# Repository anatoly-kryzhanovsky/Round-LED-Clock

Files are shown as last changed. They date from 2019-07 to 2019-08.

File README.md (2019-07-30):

# Arduino Round-LED Clock 
 Project based on awesome project <a href="https://github.com/leonvandenbeukel/Round-LED-Clock">Wi-Fi Connected Round-LED-Clock</a>
 
 # Changes from original
 1) move to <a href="https://platformio.org">PlatformIO</a> editor and split projects to separate classes
 2) support different timesources (RTC, NTP based or custom provided by your code)
 3) add new model (in progress) and PCB for RTC-based case
 4) add control block for adjust time
  
 ## Schema
 
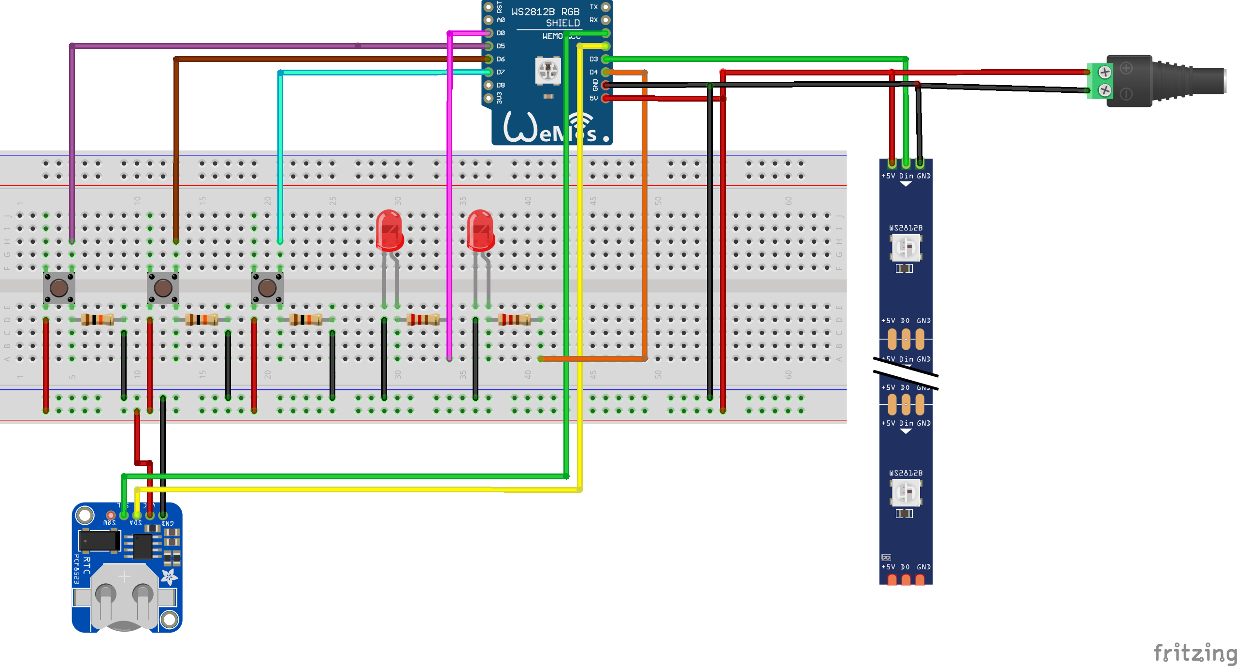
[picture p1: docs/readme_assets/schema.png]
  
 
 Connection:
 * connect 5 volts from power source to Vin pin of arduino board (Vcc, 5V, Vin,...)
 * connect 5 volts from power source to +5V of led strip
 * connect 5 volts from power source to Vcc pin of DS1307 RTC board
 * connect 5 volts from power source to three switches
 * connect Ground from power source to Gnd pin of arduino board
 * connect Ground from power source to Gnd pin of led strip
 * connect Ground from power source to Gnd pin of DS1307 RTC board
 * connect Ground from power source to another pin of switches throught 10k ohm resisors
 * connect Ground from power source to cathode (shortes) pin of two leds
 * connect three switches to digital pins of arduino board (can be any not used digital pin - pins number are configurable through code)
 * connect led anode through 220 ohm resistor to another digital pin of arduino board
 * connect SDA and SCL pins of DS1307 board to corresponding pins of your arduino board (I2C bus)
 * connect led strip data pin to not used digital pin of arduino board.  

## Notes

* There are two level of debounce - hardware (using pull-up resistor for switches) and software (using bounce2 library). You can ommit hardware part for simplification.
* You can use RTC timesource or NTP. For NTP you must have Wi-Fi with Internet access. Current NTP time source code witks only with Wemos board based on ESP8266.
* There are 60 leds in strip, each led consume 0.3W, so if you want to turn all of them you need at least 18W power adapter (with 5V). In my configuration only 3 leds turn on at same time (hour, minute and second), so i need only 0.9W or ~0.2A, so i use power adapter from my old phone.
* Be attention with power source - all units in scheme use 5V and can burn out from higher voltage
  
## Parts list (just Google on the name to find a link where to buy)

| Image | Count | Components|
| ---|---|---|
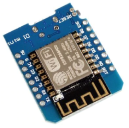
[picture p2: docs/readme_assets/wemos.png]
|  | 1 |WeMOS D1 Mini ESP module (if you want to use NTP sync) |
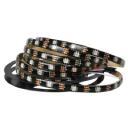
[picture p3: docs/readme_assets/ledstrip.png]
|  | 1 |LED strip WS2812B 60 RGB LED's 1 meter |
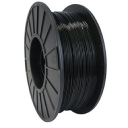
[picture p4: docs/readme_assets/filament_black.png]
|  | X | Black PLA filament |
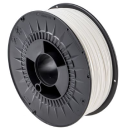
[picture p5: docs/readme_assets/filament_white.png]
|  | X | White PLA filament |
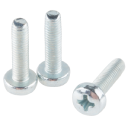
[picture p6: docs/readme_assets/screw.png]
|  | 4 | M3 screws |
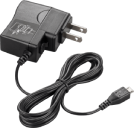
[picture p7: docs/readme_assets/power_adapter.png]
|   | 1| Power adapter (5V DC, 0.5A) |
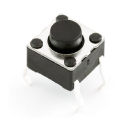
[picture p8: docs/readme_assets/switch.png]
|  | 3 | switch |
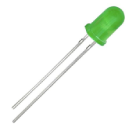
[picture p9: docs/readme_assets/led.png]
|  | 2 | leds (5V) |
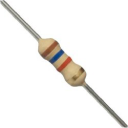
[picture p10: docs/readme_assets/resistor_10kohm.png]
|  | 3 | resistors of 10kOm |
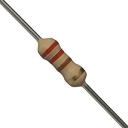
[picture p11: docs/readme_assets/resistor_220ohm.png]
|  | 2 | resistors of 220Om |
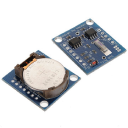
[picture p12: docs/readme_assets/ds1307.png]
|  | 1 | DS1307 RTC if you want to use RTC sync) |
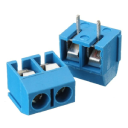
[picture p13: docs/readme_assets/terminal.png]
|  | 2 | 2 power terminal) |
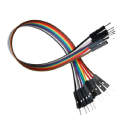
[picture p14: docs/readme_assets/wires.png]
|  | X | Jumper wires |

## YouTube video (in progress)

<a href="https://youtu.be/Z4b4v84smpg" target="_blank">Click to view: LED Clock</a>

## Configuration

All configuration stored in [LedClock/src/configuration.hpp](LedClock/src/configuration.hpp) file.

There are configurations for different part of the system:

### Control configuration (ControlConfiguration class)

* ModeButtonPin - number of digital pin where mode button was connected. Mode button allow change mode of control block. By default control block disabled. If you press mode button once then you enter to hour ajustment mode and can use increase or decrease buttons for add or substract one hour to current time. If you press mode button again then you enter to minute adjustment mode and can use increase or decrease buttons for add or substract one minute to current time. If you press mode button again you exit from edit mode and return to initial state. There is timeout for autoexit from edit mode - if you not press any button in *EditModeTimeout* period then system exit from ediit mode and return to initial state.
* IncreaseButtonPin - number of digital pin where increate button was connected. In edit mode (hour or minute) you can use this button for add one minute to current time.
* DecreaseButtonPin - number of digital pin where decrease button was connected. In edit mode (hour or minute) you can use this button for subtract one minute to current time.
* HourModeLedPin - number of digital pin where hour mode led was connected. In edit mode while you adjust hour this led is on.
* MinuteModeLedPin - number of digital pin where minute mode led was connected. In edit mode while you adjust minute this led is on.
* EditModeTimeout - timeout (in millis) for autoexit from edit mode.
* ButtonDebounceInterval - interval (in millis) for buttons debounce (used by Bounce2 library)

### Clockfact configuration (ClockFaceConfiguration class)

* HourSmoothMove - if true then at 20 minutes hour led should be at second led in hour group, if false then hour led move only after 59 minutes 59 seconds reached
* UseNightMode - use different brightness for night time (defined by *NightStartAt* and *NightEndAt*)
* NightEndAt - hours then nightmode should disabled (in 24 hour notation)
* NightStartAt - hours then nightmode should enabled (in 24 hour notation)
* NightmodeBrightness - brightness for nightmode (from 0 to 255, where 0 turn leds off and 255 - use maximum brightnes)
* LedsCount - count of leds in strip
* LedDataPin - number of digital pin where led strip data pin was connected
* ColorHour - color for hour led
* ColorMinute - color for minute led
* ColorSecond - color for second led
* ColorHourMinute - color for led if hour and minute has same position
* ColorMinuteSecond - color for led if minute and second has same position
* ColorAll - color for led if hour, minute and second has same position

### RTC timesource configuration (RtcTimeSourceConfiguration class)

* SyntInterval - interval (in millis) for synchornization internal clock (calculated by system millis() function) and external RTC

### NTP timesource configuration (NtpTimeSourceConfiguration class)

* NTPServerName - NTP server name (server should be available through WiFi)
* SSID - ssid of WiFi network
* Password - key for connect to WiFi network
* TimeZone - local timezone 
* SyncInterval - interval (in millis) for synchronization with NTP server 

### System-wide configuration (SystemConfiguration class)

* TickTime - delay (in millis) between loop iteration

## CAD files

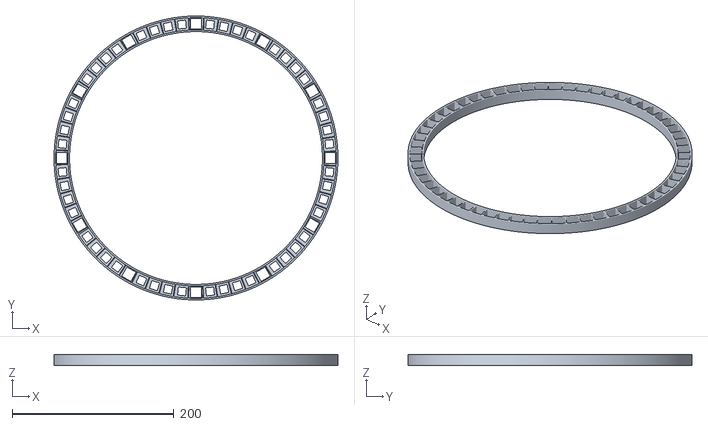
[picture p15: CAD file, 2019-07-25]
docs/STL/Segment complete thicker wall.stl
350.9 x 350.9 x 13.2

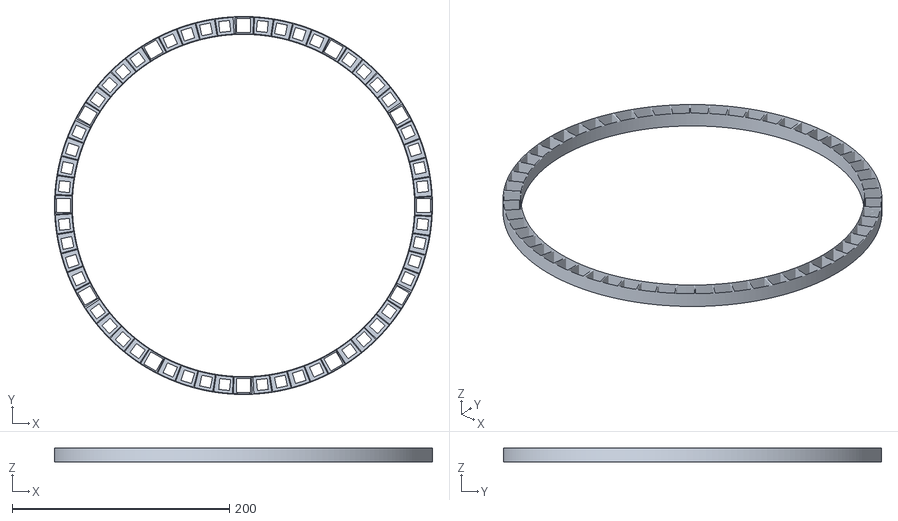
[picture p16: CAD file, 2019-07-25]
docs/STL/Segment complete.stl
348.1 x 348.1 x 13.2

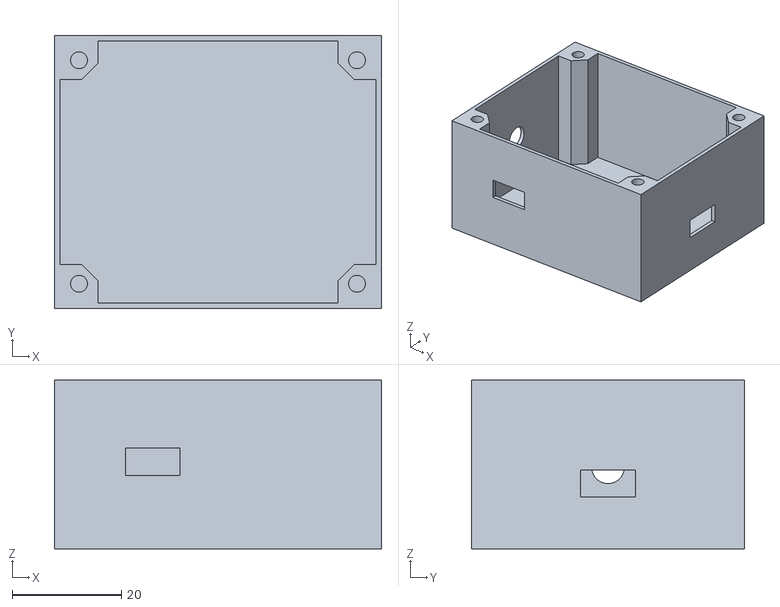
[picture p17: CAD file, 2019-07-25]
docs/STL/Box.stl
60.0 x 50.0 x 31.0

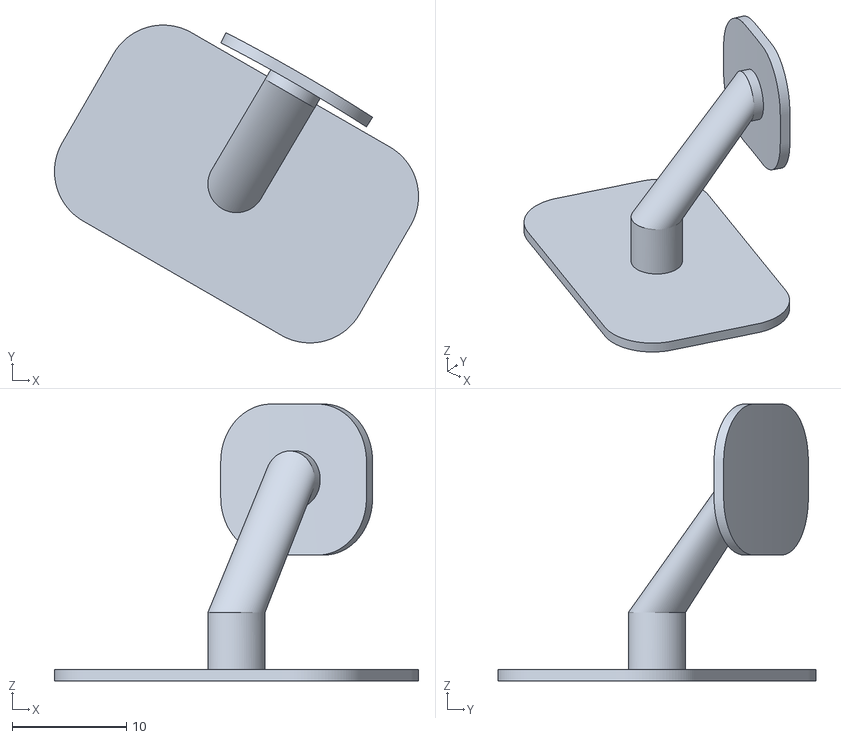
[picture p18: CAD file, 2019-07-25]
docs/STL/Holder Small.stl
31.8 x 27.8 x 24.2

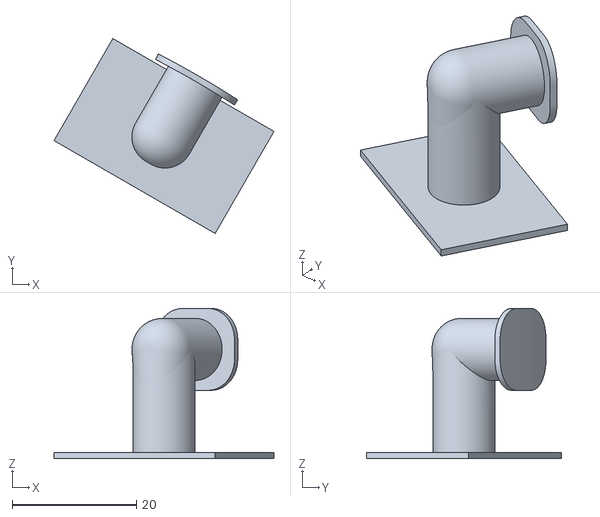
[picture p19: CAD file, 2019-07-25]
docs/STL/Holder Large.stl
35.5 x 31.4 x 24.2

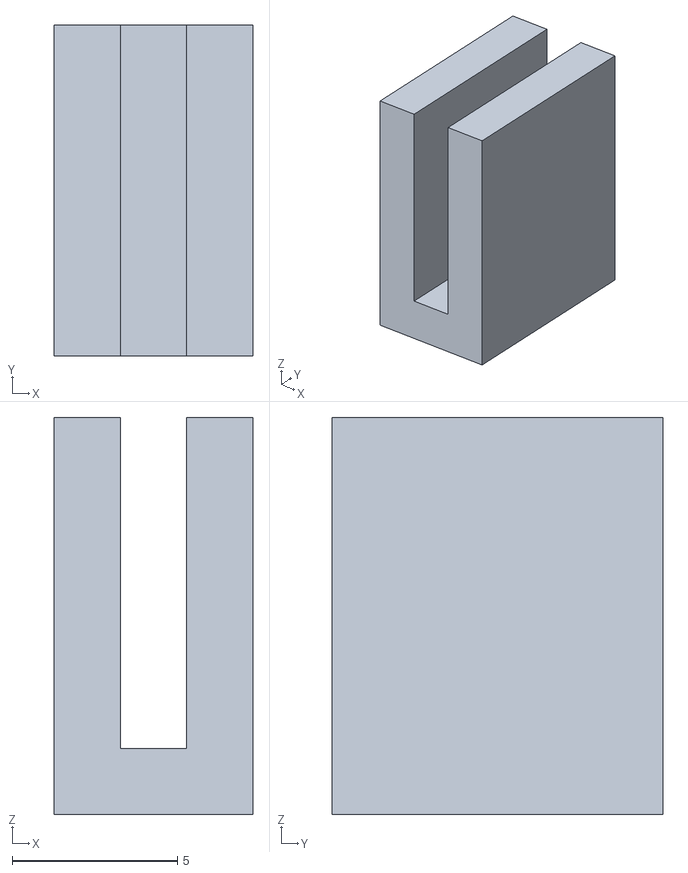
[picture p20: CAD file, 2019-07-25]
docs/STL/lock.STL
6.00 x 10.0 x 12.0

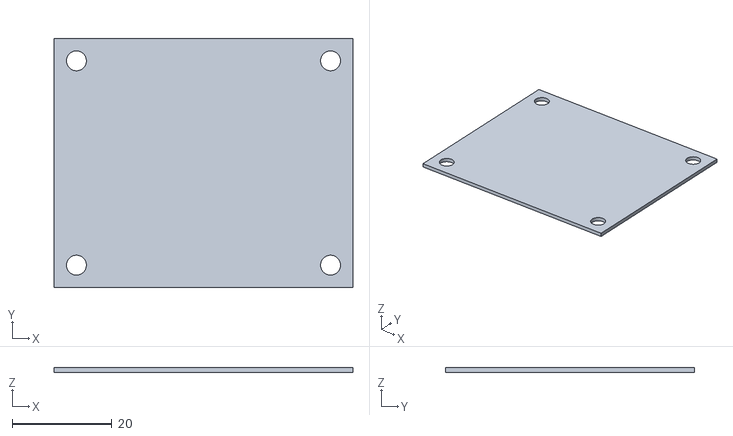
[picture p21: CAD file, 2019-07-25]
docs/STL/Lid.stl
60.0 x 50.0 x 1.00

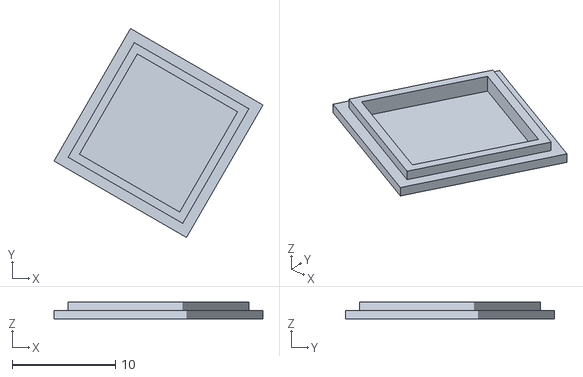
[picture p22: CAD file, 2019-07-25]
docs/STL/Cover Large.stl
20.2 x 20.2 x 1.60

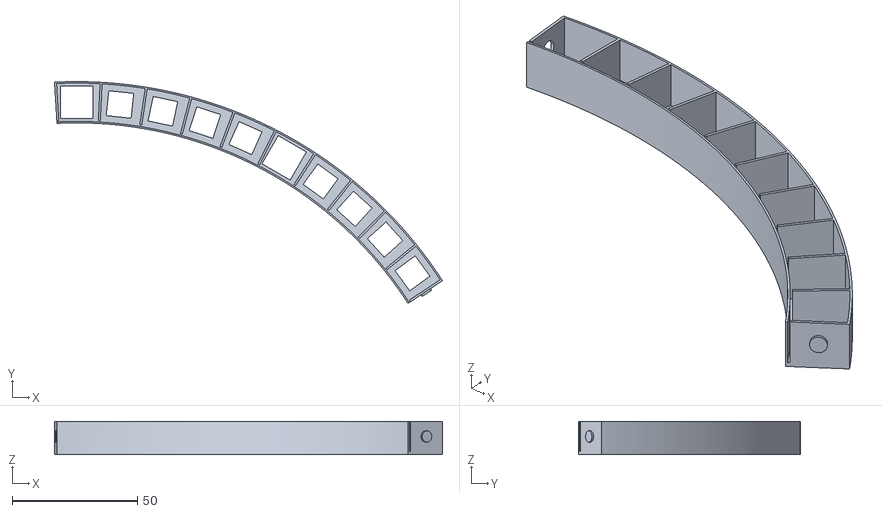
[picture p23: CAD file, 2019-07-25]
docs/STL/Segment.stl
154.9 x 88.6 x 13.2

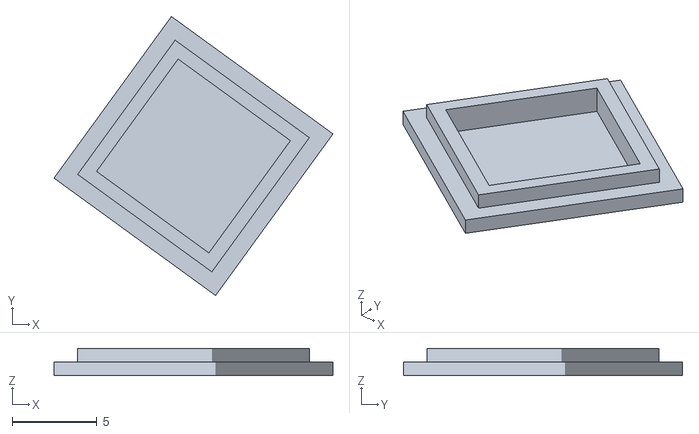
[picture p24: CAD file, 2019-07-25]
docs/STL/Cover Small.stl
16.5 x 16.5 x 1.60

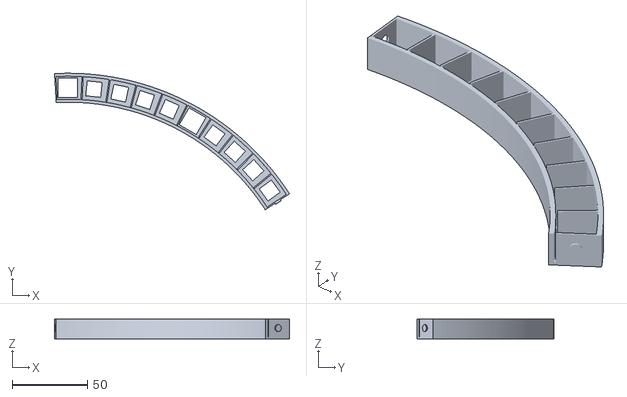
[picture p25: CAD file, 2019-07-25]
docs/STL/Segment thicker wall.stl
156.2 x 90.7 x 13.2

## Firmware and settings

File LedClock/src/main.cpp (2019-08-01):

#include <Arduino.h>

#include <time.hpp>
#include <rtcTimeSource.hpp>
#include <ntpTimeSource.hpp>
#include <clockControl.hpp>
#include <clockFace.hpp>
#include <configuration.hpp>

#define DEBUG

RtcTimeSource timeSource;
//NtpTimeSource timeSource;

ClockControl control(&timeSource);
ClockFace clockFace;

unsigned long lastDebugTime = 0;

void setup() {
  Serial.begin(115200);

  control.init();
  timeSource.init();
  clockFace.init();
}

void loop() {
  timeSource.updateTime();
  control.update();
  clockFace.showTime(timeSource.getCurrentTime());

#ifdef DEBUG
  if(millis() - lastDebugTime > 5000)
  {
    lastDebugTime = millis();
    Serial.println("TimeSource state");
    Serial.println(timeSource.toString());
    Serial.println("Control state");
    Serial.println(control.toString());
    Serial.println("ClockFace state");
    Serial.println(clockFace.toString());
  }
#endif
 
  delay(Configuration::SystemConfiguration::TickTime);
}

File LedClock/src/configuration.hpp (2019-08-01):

#pragma once

#include <FastLED.h>

class Configuration {
    public:
    //configuration for control module
    class ControlConfiguration {
        public:
            //pin number for mode button (none/clock/minutes control)
            static const int ModeButtonPin           = D6;

            //pin number for increase button (add hour or minute)
            static const int IncreaseButtonPin       = D5;

            //pin number for decrease button (substract hour or minute)
            static const int DecreaseButtonPin       = D0;

            //pin number for set hours mode led
            static const int HourModeLedPin          = D4;

            //pin number for set minutes mode led
            static const int MinuteModeLedPin        = D3;

            //timeout (in millis) for autoexit from set time mode
            static const int EditModeTimeout         = 5000;

            //edbounce interval for Bounce2 (millis)
            static const int ButtonDebounceInterval  = 5;
    };

    //configuration for clockface
    class ClockFaceConfiguration {
        public:        
            //led number for zero count
            static const int ZeroLed                 = 30;

            //direction for leds numbering (+1 for clockwise, -1 for counterclockwise)
            static const int Direction               = -1;

            //enable move hour led between interger parts (i.e. if true then at 20 minutes hour led should be at second led in hour group, if false then hour led move only after 59 minutes 59 seconds reached)
            static const bool HourSmoothMove         = true;

            //use different brightness for night hours
            static const bool UseNightMode           = false;

            //hours when night node should be deactivated
            static const int NightEndAt              = 8;

            //hours when night node should be activated
            static const int NightStartAt            = 20;

            //brightness for nightmod
            static const int NightModeBrightness     = 20;

            //leds count in strip
            static const int LedsCount               = 60;

            //pin for led strip data
            static const int LedDataPin              = D7;

            //color for hour led
            static const CRGB ColorHour;

            //color for minute led
            static const CRGB ColorMinute;

            //color for second led
            static const CRGB ColorSecond;

            //color for led if hours and minutes in same position
            static const CRGB ColorHourMinute;

            //color for led if hours and seconds in same position
            static const CRGB ColorHourSecond;

            //color for led if minutes and seconds in same position
            static const CRGB ColorMinuteSecond;

            //color for led if hours, minutes and seconds in same position
            static const CRGB ColorAll;
    };

    //configuration for RTC timesource
    class RtcTimeSourceConfiguration {
        public:
            //sync internal timer with timesource (millis)
            static const unsigned long SyncInterval = 60000L;
    };

    //config for NTP timesource
    class NtpTimeSourceConfiguration {
        public:
            static const char* NTPServerName;
            static const char* SSID;
            static const char* Password;
            static const unsigned long TimeZone = 1;

            //sync internal timer with timesource (millis)
            static const unsigned long SyncInterval = 60000L;
    };
        
    //global configuration
    class SystemConfiguration {
        public:
            //delay (millis) between update iteration
            static const int TickTime               = 20;
    };       
};

const CRGB Configuration::ClockFaceConfiguration::ColorHour              = CRGB::Red;
const CRGB Configuration::ClockFaceConfiguration::ColorMinute            = CRGB::Green;
const CRGB Configuration::ClockFaceConfiguration::ColorSecond            = CRGB::Blue;
const CRGB Configuration::ClockFaceConfiguration::ColorHourMinute        = CRGB::Yellow;
const CRGB Configuration::ClockFaceConfiguration::ColorHourSecond        = CRGB::Magenta;
const CRGB Configuration::ClockFaceConfiguration::ColorMinuteSecond      = CRGB::Cyan;
const CRGB Configuration::ClockFaceConfiguration::ColorAll               = CRGB::White;

const char* Configuration::NtpTimeSourceConfiguration::NTPServerName = "ntp1.stratum2.ru";
const char* Configuration::NtpTimeSourceConfiguration::SSID = "";
const char* Configuration::NtpTimeSourceConfiguration::Password = "";

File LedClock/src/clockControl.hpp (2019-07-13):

#pragma once

#include <Arduino.h>
#include <Bounce2.h>

#include <timeSource.h>
#include <configuration.hpp>

class ClockControl {        
    enum SystemMode {
        Normal,
        Hours,
        Minutes
    };

    private:
        static char* _buffer;

    private:
        TimeSource* _timeSource;
        bool _increaseButtonPressed;
        bool _decreaseButtonPressed;
        bool _modeButtonPressed;
        unsigned long _prevModeChange;
        SystemMode _currentMode;
        Bounce _modeDebouncer;
        Bounce _increaseDebouncer;
        Bounce _decreaseDebouncer;        
    
    public:
        ClockControl(TimeSource* _timeSource): 
            _timeSource(_timeSource), _increaseButtonPressed(false), _decreaseButtonPressed(false), _modeButtonPressed(false), _prevModeChange(0),  _currentMode (SystemMode::Normal) {                                   
        }

        const char* toString() {
            const char* modeName = "Normal";
            if(_currentMode == SystemMode::Hours)
                modeName = "Hours";
            if(_currentMode == SystemMode::Minutes)
                modeName = "Minutes";

            sprintf(
                _buffer, 
                "ModeButton: %s, IncreaseButton: %s, DecreaseButton: %s, CurrentState: %s, Last action time: %ld", 
                _modeButtonPressed ? "pressed": "normal",
                _increaseButtonPressed ? "pressed": "normal",
                _decreaseButtonPressed ? "pressed": "normal",
                modeName,
                millis() - _prevModeChange);            
            
            return _buffer;
        }

        void init() {
            pinMode(Configuration::ControlConfiguration::ModeButtonPin, INPUT);
            pinMode(Configuration::ControlConfiguration::IncreaseButtonPin, INPUT);
            pinMode(Configuration::ControlConfiguration::DecreaseButtonPin, INPUT);
            pinMode(Configuration::ControlConfiguration::HourModeLedPin, OUTPUT);
            pinMode(Configuration::ControlConfiguration::MinuteModeLedPin, OUTPUT);

            _modeDebouncer.attach(Configuration::ControlConfiguration::ModeButtonPin);
            _modeDebouncer.interval(Configuration::ControlConfiguration::ButtonDebounceInterval);

            _increaseDebouncer.attach(Configuration::ControlConfiguration::IncreaseButtonPin);
            _increaseDebouncer.interval(Configuration::ControlConfiguration::ButtonDebounceInterval);

            _decreaseDebouncer.attach(Configuration::ControlConfiguration::DecreaseButtonPin);
            _decreaseDebouncer.interval(Configuration::ControlConfiguration::ButtonDebounceInterval);

            _currentMode = SystemMode::Normal;

            _prevModeChange = 0;
        }

        void update() {
            _modeDebouncer.update();
            _increaseDebouncer.update();
            _decreaseDebouncer.update();

            bool modeButtonPressed = _modeDebouncer.read() == HIGH;
            if(modeButtonPressed && modeButtonPressed != _modeButtonPressed) {
                switch(_currentMode) {
                    case SystemMode::Normal:
                        _currentMode = SystemMode::Hours;
                        digitalWrite(Configuration::ControlConfiguration::HourModeLedPin, HIGH);
                        digitalWrite(Configuration::ControlConfiguration::MinuteModeLedPin, LOW);
                        break;

                    case SystemMode::Hours:
                        _currentMode = SystemMode::Minutes;
                        digitalWrite(Configuration::ControlConfiguration::HourModeLedPin, LOW);
                        digitalWrite(Configuration::ControlConfiguration::MinuteModeLedPin, HIGH);
                        break;

                    case SystemMode::Minutes:
                        _currentMode = SystemMode::Normal;
                        digitalWrite(Configuration::ControlConfiguration::HourModeLedPin, LOW);
                        digitalWrite(Configuration::ControlConfiguration::MinuteModeLedPin, LOW);
                        break;
                }

                _prevModeChange = millis();
            }

            _modeButtonPressed = modeButtonPressed;

            int dHours = 0, dMinutes = 0;
            Time currentTime = _timeSource->getCurrentTime();

            bool increaseButtonPressed = _increaseDebouncer.read() == HIGH;
            if(increaseButtonPressed && _increaseButtonPressed != increaseButtonPressed) {
                switch(_currentMode) {
                    case SystemMode::Hours:
                        dHours = 1;
                        break;

                    case SystemMode::Minutes:
                        if(currentTime.getMinutes() == 59)
                            dHours = -1;
                        dMinutes = 1;
                        break;

                    default:
                        break;
                }

                _prevModeChange = millis();
            }

            _increaseButtonPressed = increaseButtonPressed;
           
            bool decreaseButtonPressed = _decreaseDebouncer.read() == HIGH;            
            if(decreaseButtonPressed && _decreaseButtonPressed != decreaseButtonPressed) {
                switch(_currentMode) {
                    case SystemMode::Hours:
                        dHours = -1;
                        break;

                    case SystemMode::Minutes:
                        if(currentTime.getMinutes() == 0)
                            dHours = 1;
                        dMinutes = -1;
                        break;

                    default:
                        break;
                }

                _prevModeChange = millis();
            }

            _decreaseButtonPressed = decreaseButtonPressed;

            _timeSource->adjustTime(dHours, dMinutes);   

            if(millis() - _prevModeChange > Configuration::ControlConfiguration::EditModeTimeout) {
                digitalWrite(Configuration::ControlConfiguration::HourModeLedPin, LOW);
                digitalWrite(Configuration::ControlConfiguration::MinuteModeLedPin, LOW);
                _currentMode = SystemMode::Normal;
            }         
        }        
};

char* ClockControl::_buffer = new char[255];

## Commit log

2019-07-13 fix time and rtcTimeSource class
    [clockControl.hpp, configuration.hpp, main.cpp]
2019-07-25 add toString method, fix small issues
    [configuration.hpp, ntpTimeSource.hpp]
2019-07-25 add control block pcb
2019-07-25 move stl do docs folder, add lock model
    [Box.stl, Cover Large.stl, Cover Small.stl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]
2019-07-30 fix pcb layout
2019-08-01 fix leds addressing
